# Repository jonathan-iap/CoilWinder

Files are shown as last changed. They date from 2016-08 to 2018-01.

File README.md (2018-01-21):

# CoilWinder

## Version : 1

### Abstract :

An evolutive coil winder machine based on *Arduino*.
The format of this machine can easily be adapted and upgraded for any coils.

---

### State of development :

  * Hardware -> functional
  * Software -> v1.0 : ok for coils production. Homing not working properly.

Software is write with the help of *platformIO* and *Eclipse*.
If you want to compile with *Arduino IDE* you need to create _*.ino_ file and add librairies in your path.

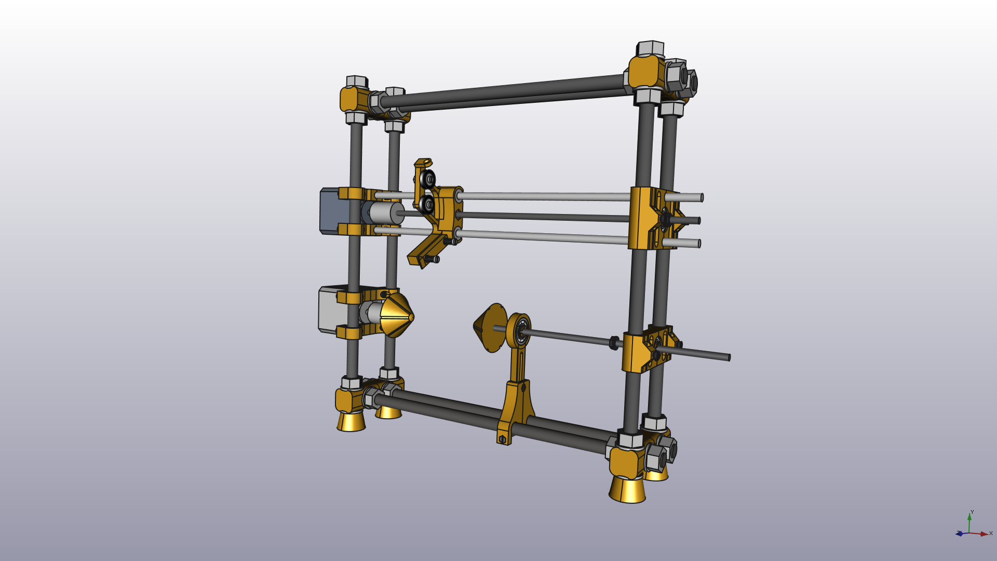
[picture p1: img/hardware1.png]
alt text Hardware view 1


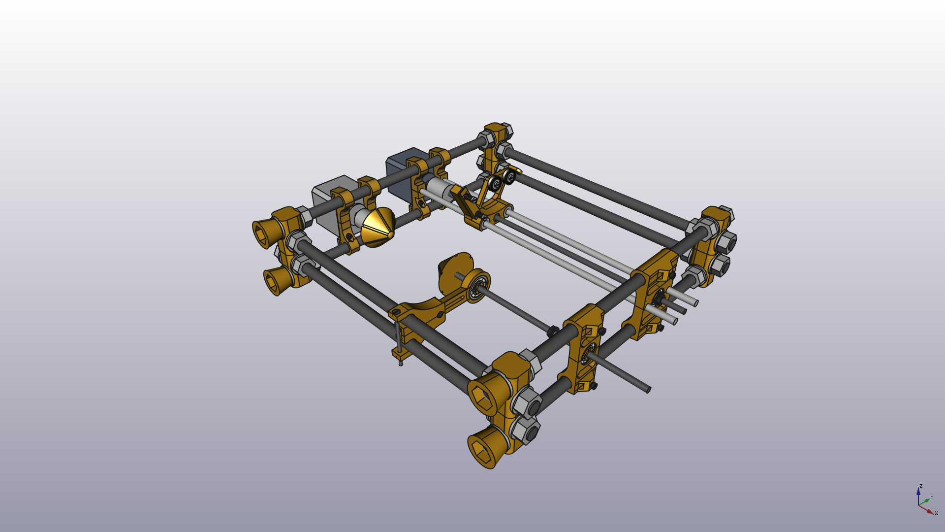
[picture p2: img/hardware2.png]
alt text Hardware view 2


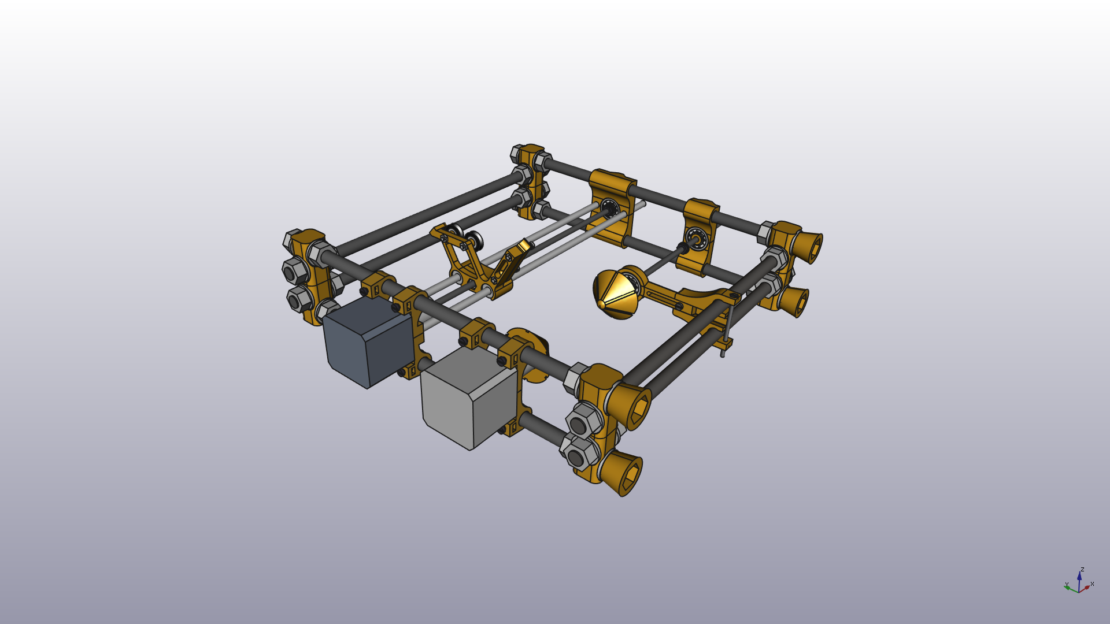
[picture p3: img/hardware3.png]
alt text Hardware view 3


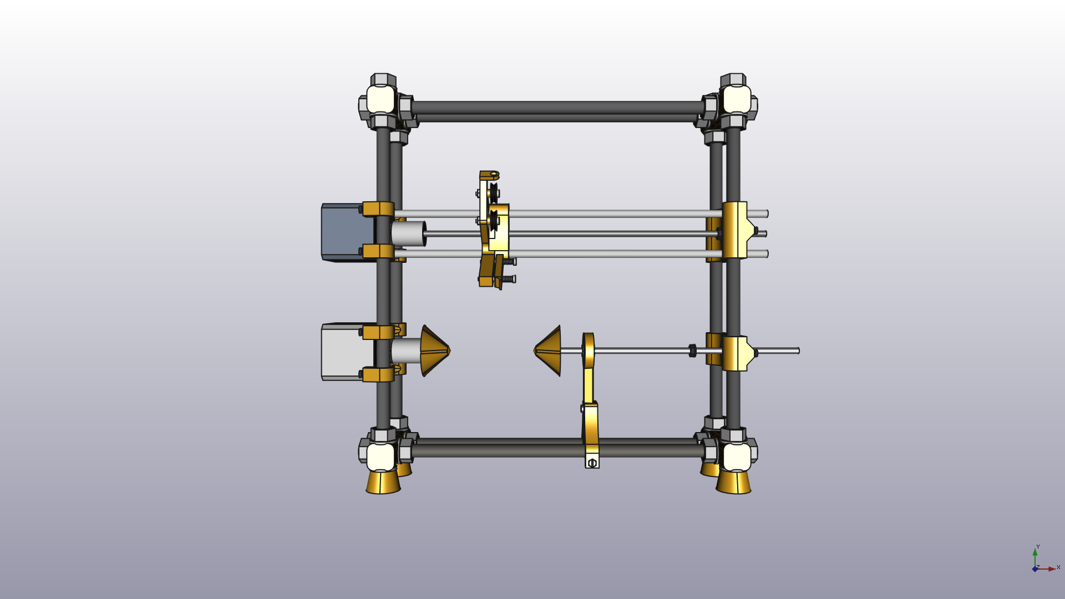
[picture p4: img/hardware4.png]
alt text Hardware view 4


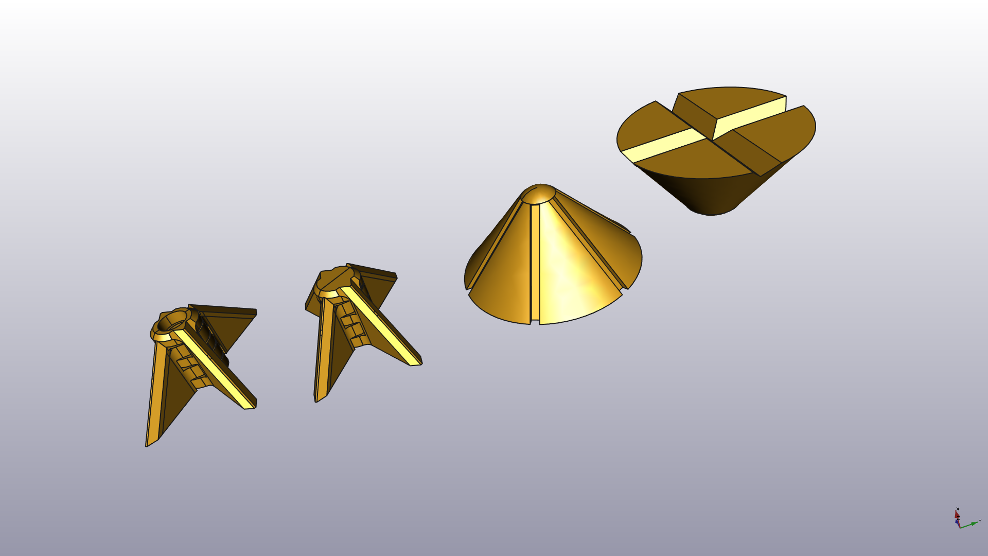
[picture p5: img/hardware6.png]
alt text Hardware view 6


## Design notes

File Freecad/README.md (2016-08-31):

# FreeCAD

Version used : 0.16
Macros used : bolts

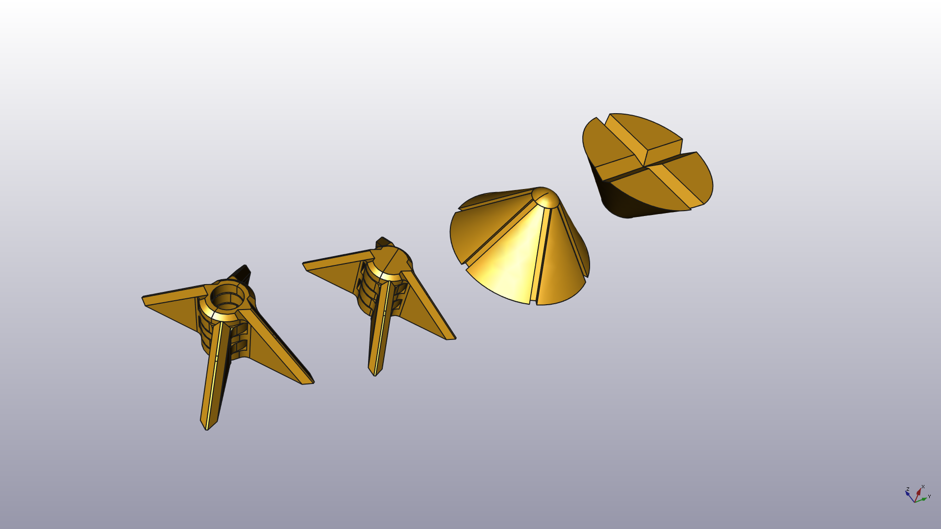
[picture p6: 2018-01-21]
img/hardware5.png

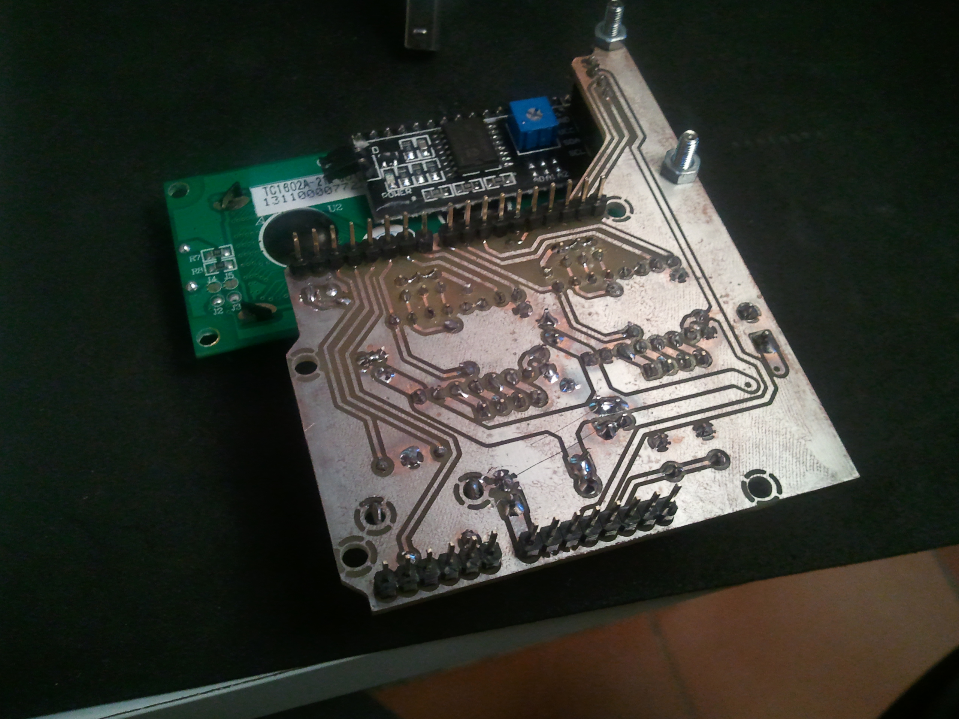
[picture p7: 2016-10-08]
img/2016-10-08 19.10.06.jpg

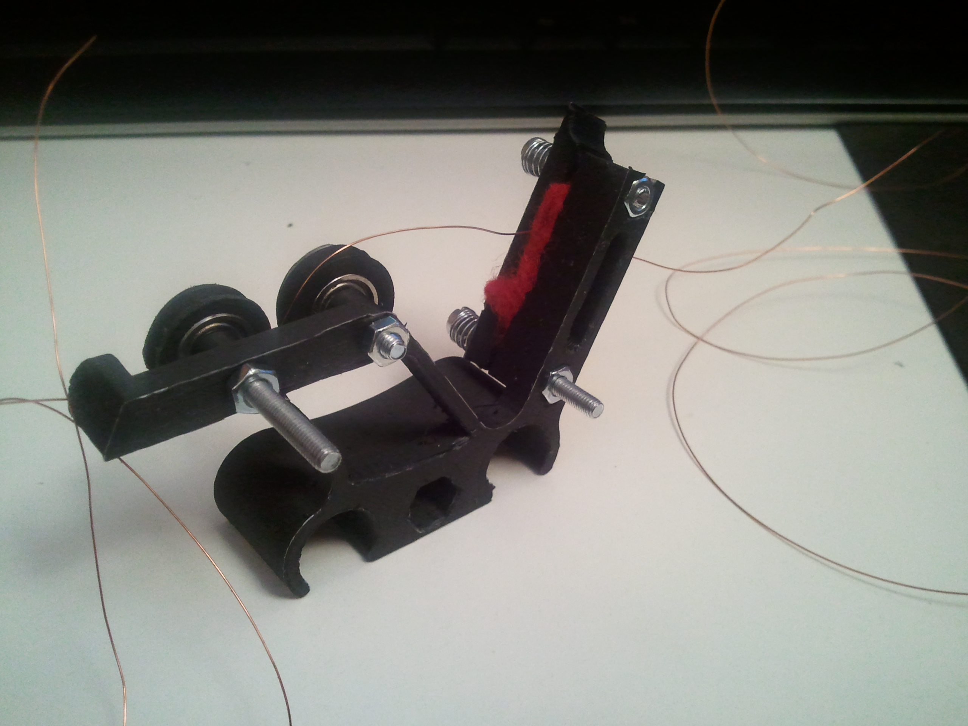
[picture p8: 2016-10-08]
img/2016-10-08 19.16.13.jpg

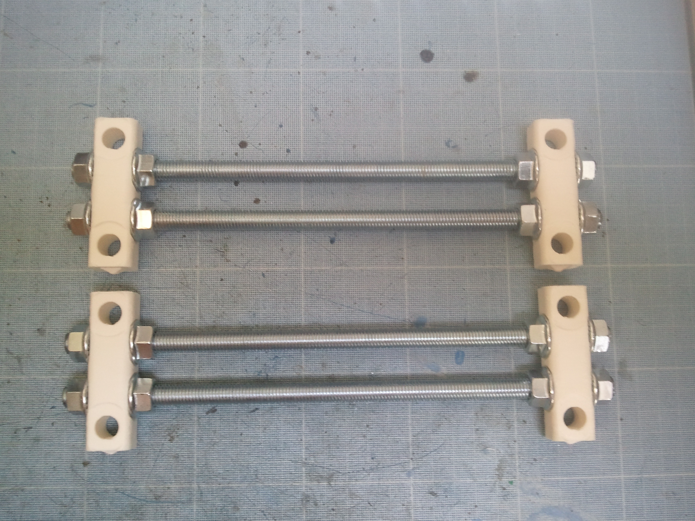
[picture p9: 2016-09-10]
img/2016-09-10 18.19.24.jpg

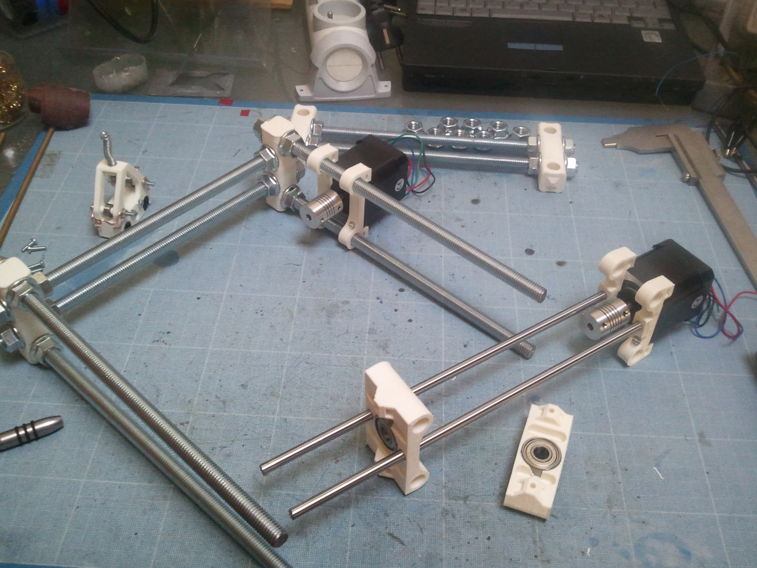
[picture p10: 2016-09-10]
img/2016-09-10 19.29.03.jpg

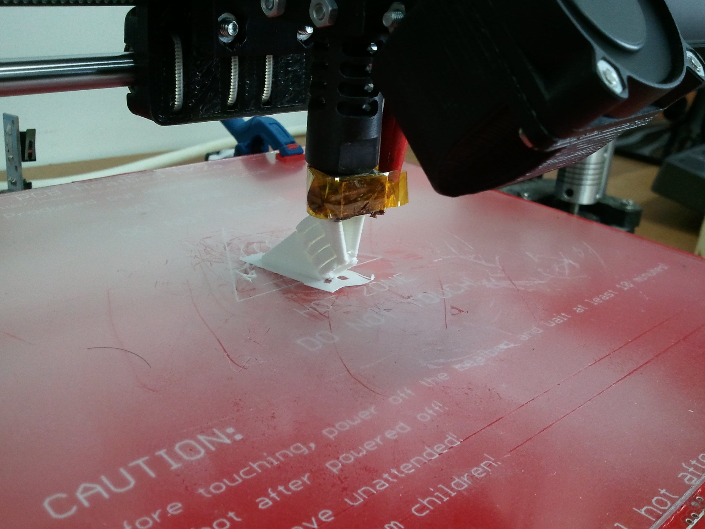
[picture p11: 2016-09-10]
img/2016-08-17 15.03.10.jpg

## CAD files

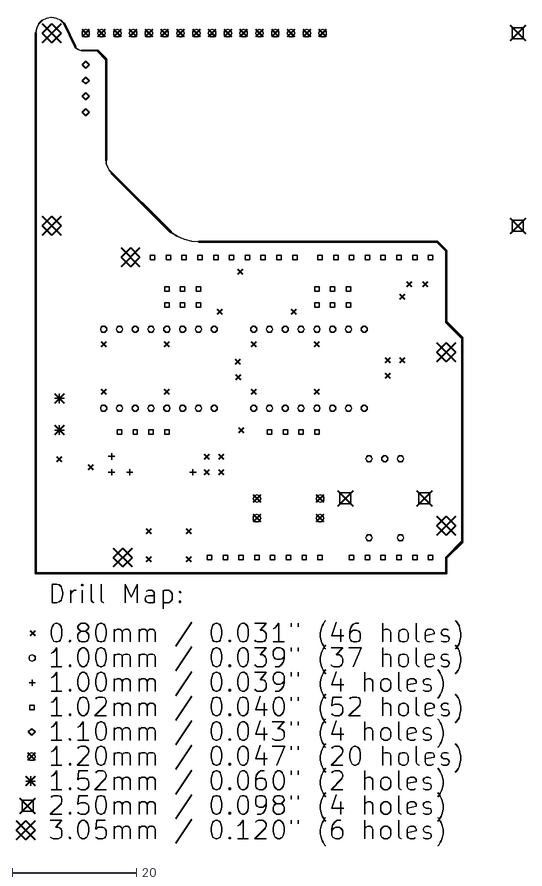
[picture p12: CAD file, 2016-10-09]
Kicad/shield_coil-winder/FAB/V1.1/shield_coil-winder-drl_map.dxf
81.9 x 133.5

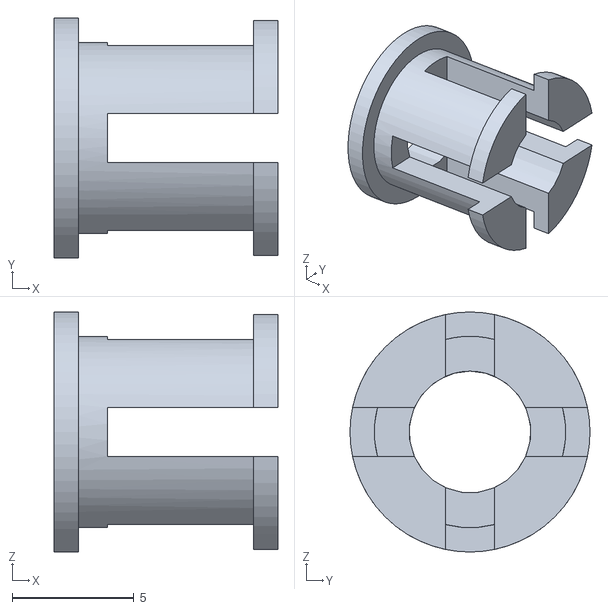
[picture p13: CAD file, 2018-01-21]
STL_export/entretoise pour roulement.stl
9.20 x 9.86 x 9.86

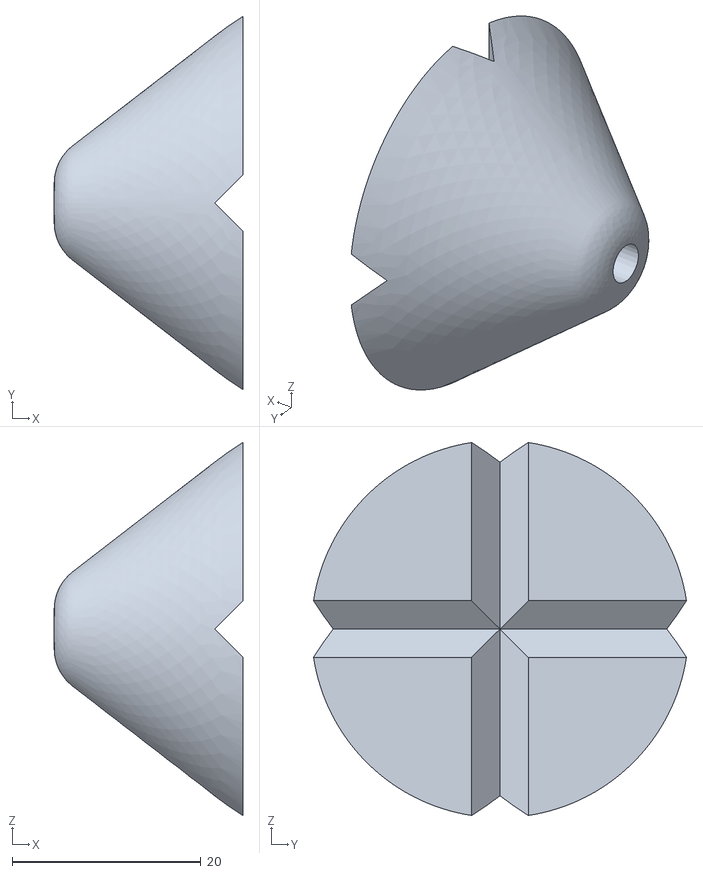
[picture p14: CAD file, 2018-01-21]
STL_export/centreur fixe pour plaque.stl
20.0 x 39.5 x 39.5

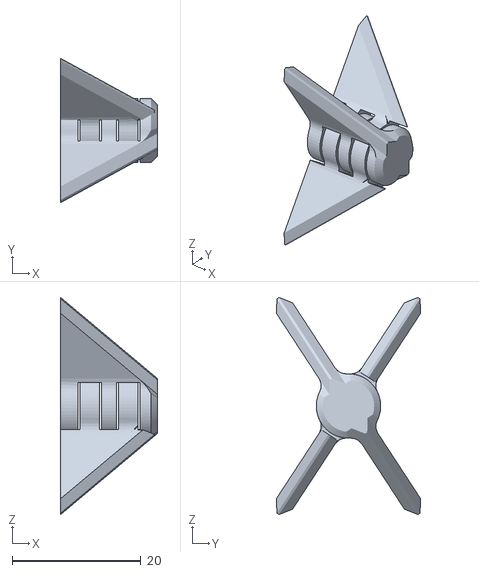
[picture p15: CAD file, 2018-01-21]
STL_export/centreur variable.stl
15.0 x 22.4 x 33.7

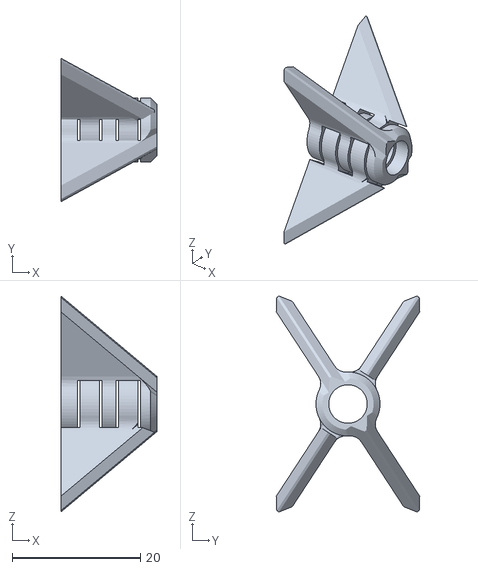
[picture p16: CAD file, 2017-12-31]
STL_export/centreur variable traversant.stl
15.0 x 22.4 x 33.7

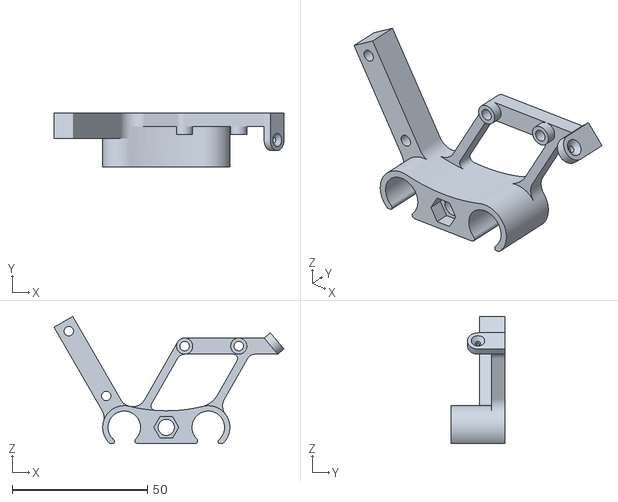
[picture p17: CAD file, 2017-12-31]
STL_export/Chariot_v0.4-LM6UU.stl
84.9 x 20.0 x 47.0

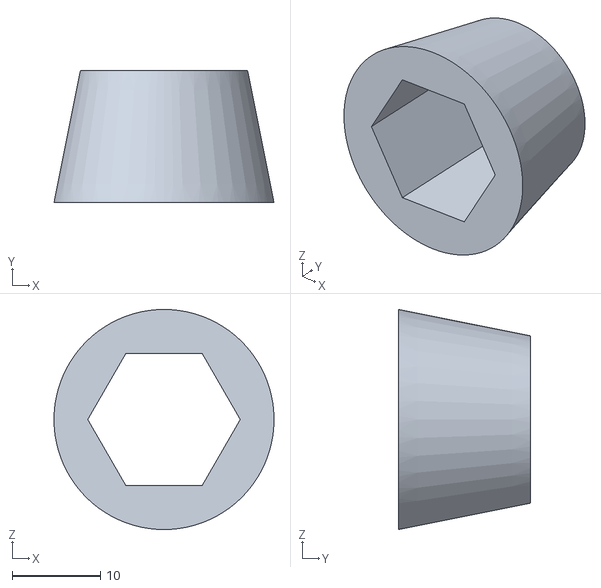
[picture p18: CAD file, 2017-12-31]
STL_export/pied.stl
25.0 x 15.0 x 25.0

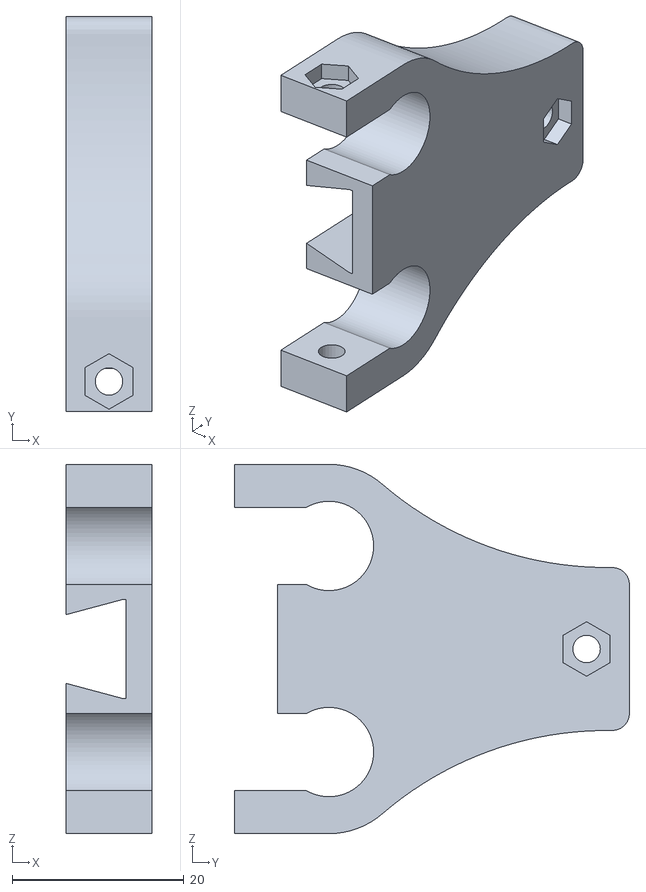
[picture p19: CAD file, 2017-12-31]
STL_export/bride axial.stl
10.0 x 46.0 x 43.0

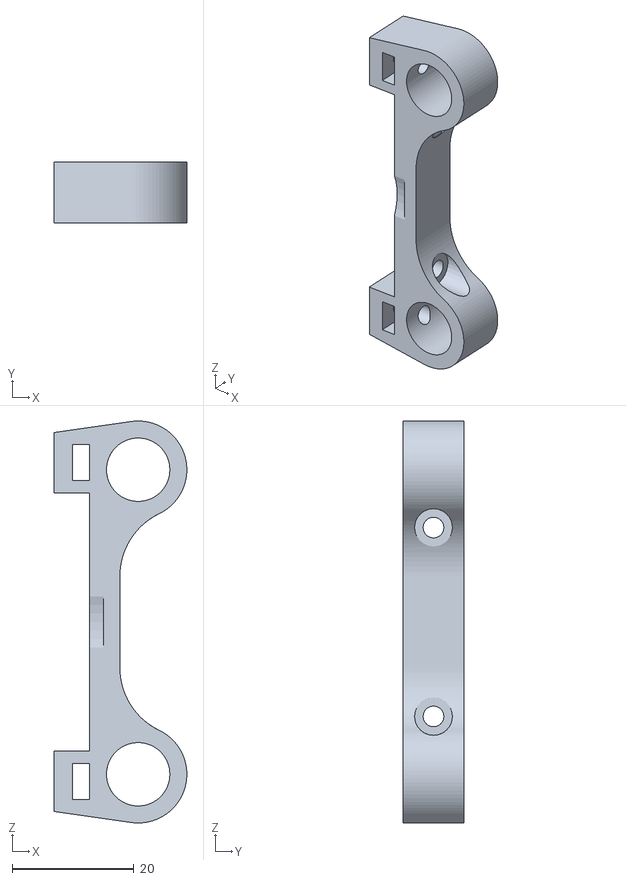
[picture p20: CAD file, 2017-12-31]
STL_export/support moteur bobine.stl
21.8 x 10.0 x 66.0

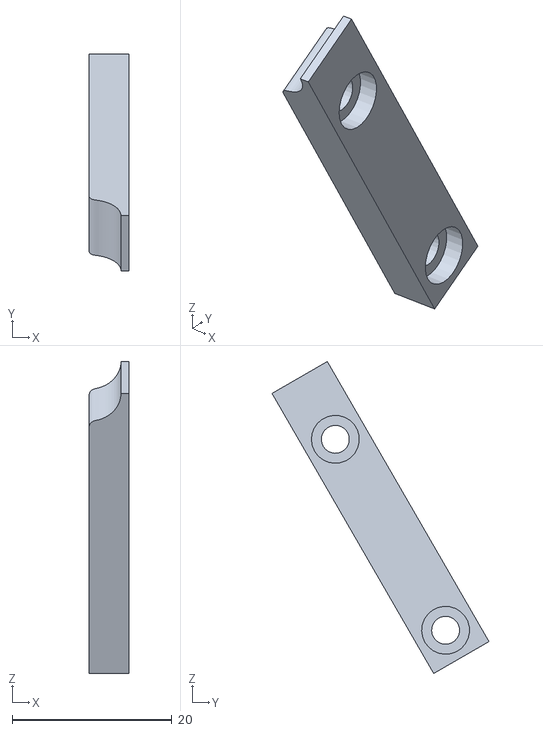
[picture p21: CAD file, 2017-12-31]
STL_export/patin pour chariot_v0.4.stl
5.00 x 27.2 x 39.1

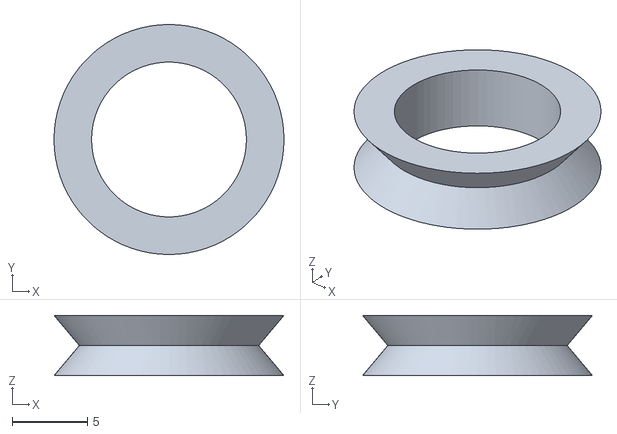
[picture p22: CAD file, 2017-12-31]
STL_export/poulie roulement 10x3x5.stl
15.3 x 15.3 x 4.00

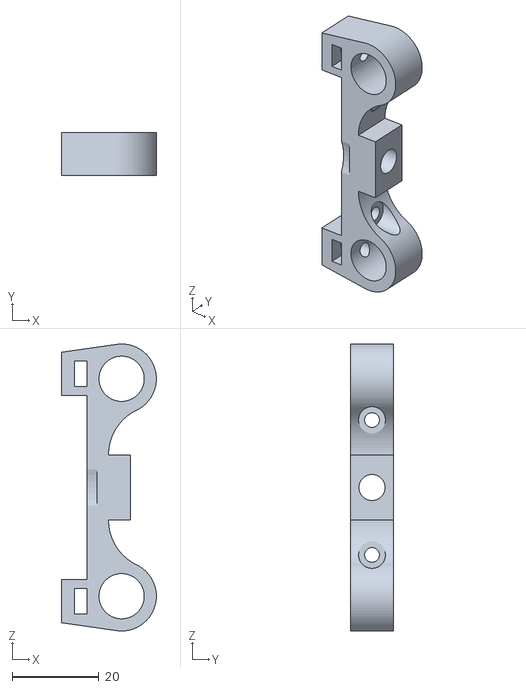
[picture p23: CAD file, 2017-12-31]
STL_export/support moteur chariot.stl
21.8 x 10.0 x 66.0

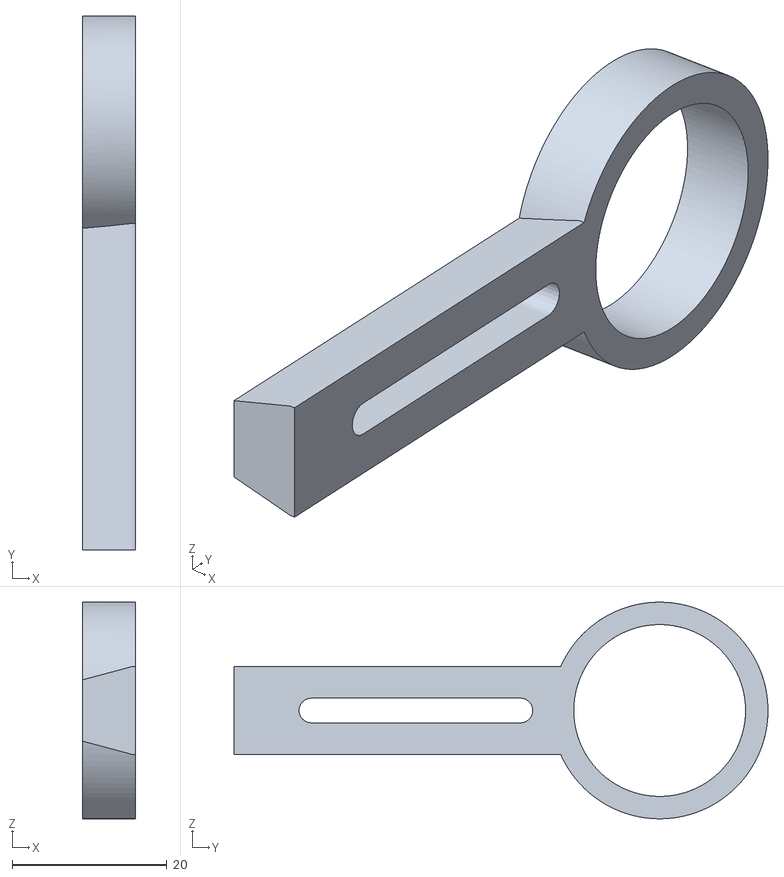
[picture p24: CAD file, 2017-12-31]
STL_export/support de bride axial.stl
6.90 x 69.0 x 28.0

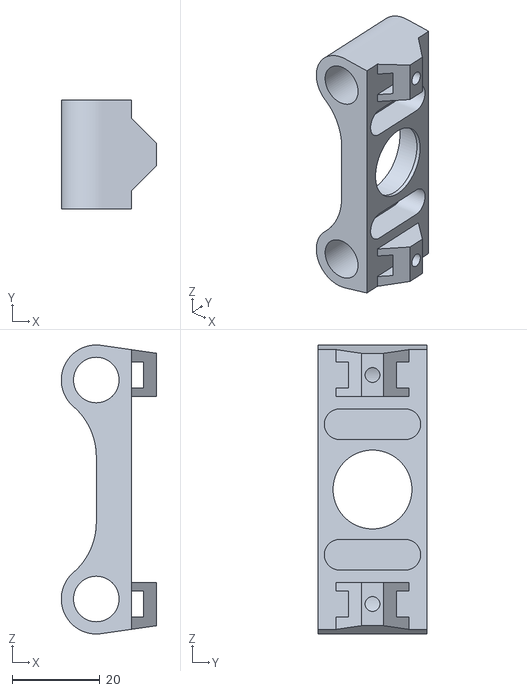
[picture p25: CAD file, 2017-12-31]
STL_export/support axe bobine_v0.2.stl
21.8 x 25.0 x 66.0

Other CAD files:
STL_export/centreur fixe conique.stl
STL_export/Chariot_v0.4-6x10x8.stl
STL_export/coin.stl
STL_export/support axe guide fil_v0.2.stl
Kicad/shield_coil-winder/FAB/V1.0/shield_coil-winder-drl_map.dxf

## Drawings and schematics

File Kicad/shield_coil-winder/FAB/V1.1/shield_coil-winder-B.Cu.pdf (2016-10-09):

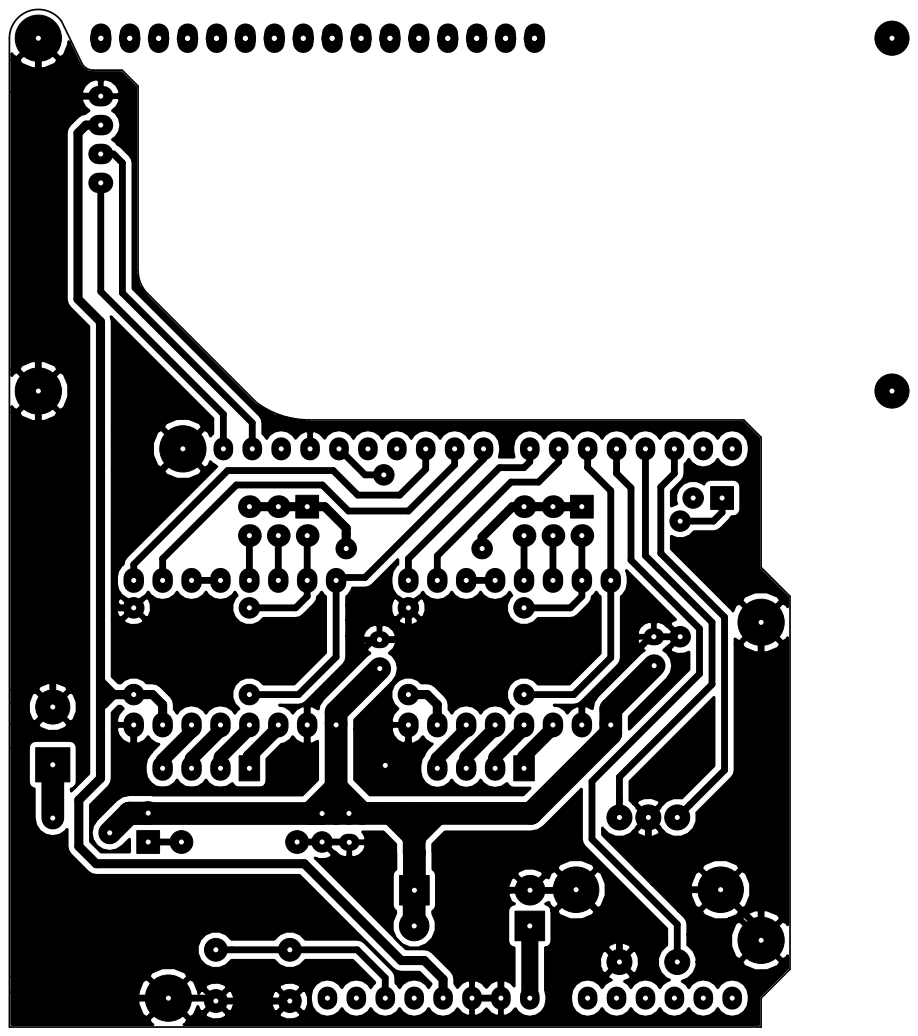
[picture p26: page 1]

Adding power status LED
File: shield_coil-winder.kicad_pcb Sheet: Author : Jonathan IAPICCO Correction footprint rotary encoder

Id: 1/1 Title: Shield coil winder for arduino UNO

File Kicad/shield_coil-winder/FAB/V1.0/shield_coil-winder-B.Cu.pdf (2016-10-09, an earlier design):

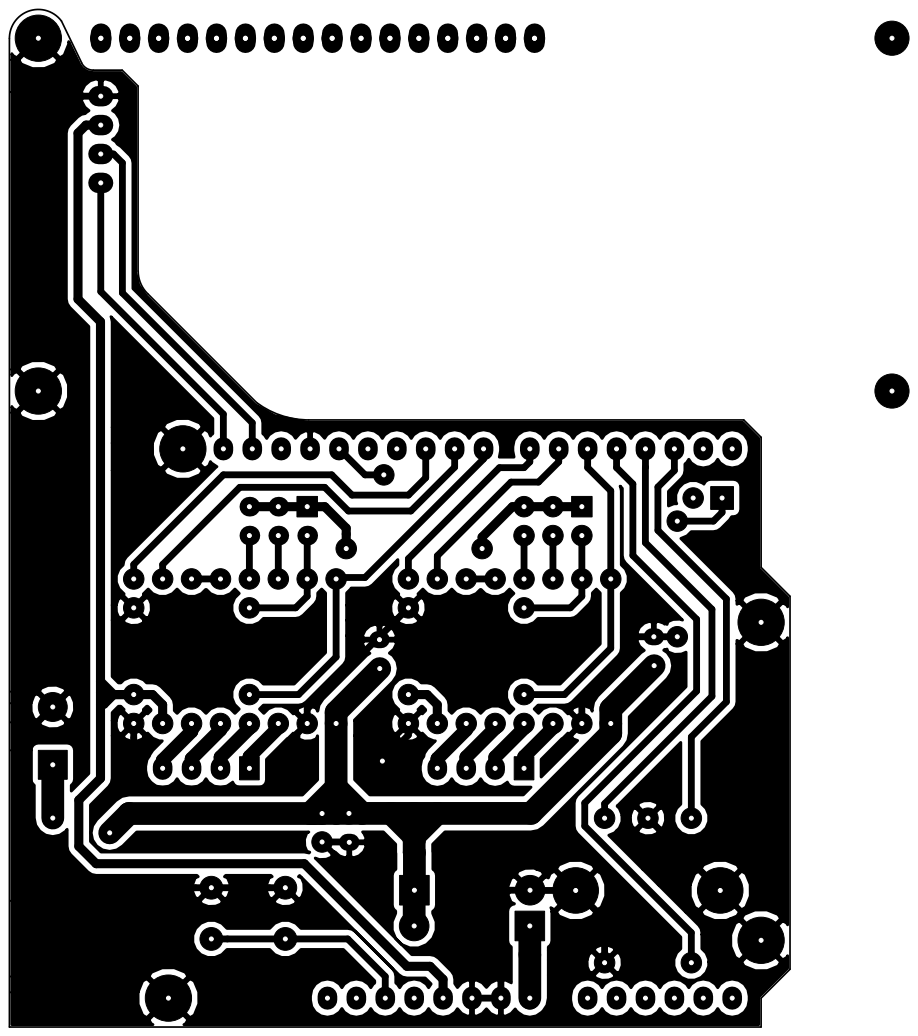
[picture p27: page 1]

File: shield_coil-winder.kicad_pcb Sheet: Author : Jonathan IAPICCO

Id: 1/1 Title: Shield coil winder for arduino UNO

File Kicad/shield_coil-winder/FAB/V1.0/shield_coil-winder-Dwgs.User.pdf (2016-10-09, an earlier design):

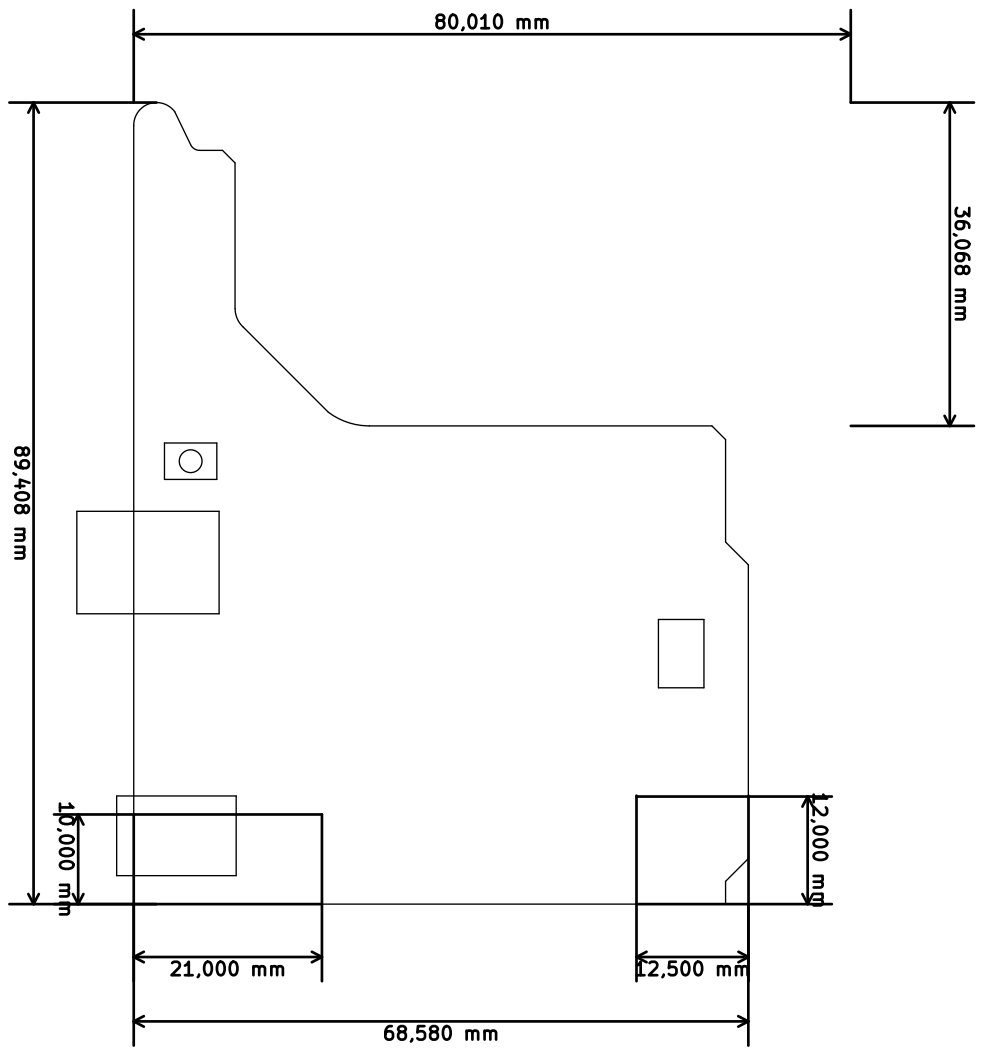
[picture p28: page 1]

File: shield_coil-winder.kicad_pcb Sheet: Author : Jonathan IAPICCO 36,068 mm

Id: 1/1 Title: Shield coil winder for arduino UNO

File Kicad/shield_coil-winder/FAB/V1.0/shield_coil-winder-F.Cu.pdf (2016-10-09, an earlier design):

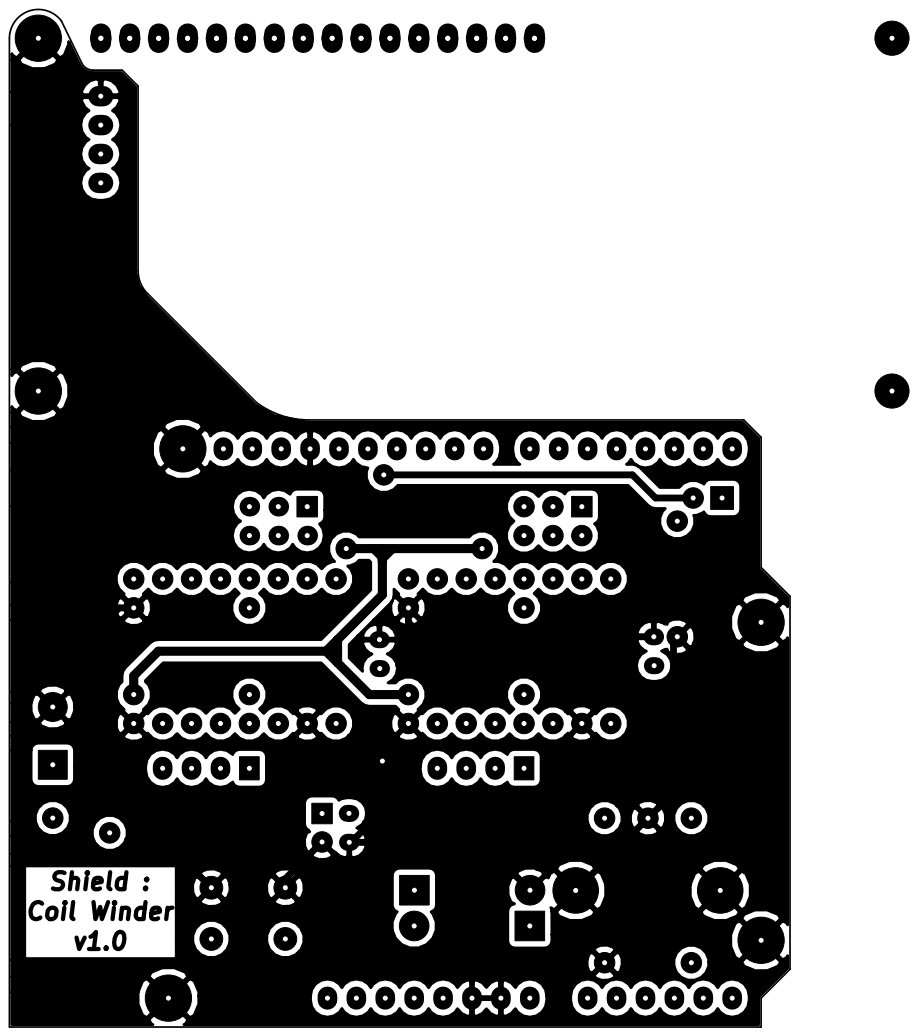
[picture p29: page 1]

File: shield_coil-winder.kicad_pcb Sheet: Author : Jonathan IAPICCO Shield : Coil Winder v1.0

Id: 1/1 Title: Shield coil winder for arduino UNO

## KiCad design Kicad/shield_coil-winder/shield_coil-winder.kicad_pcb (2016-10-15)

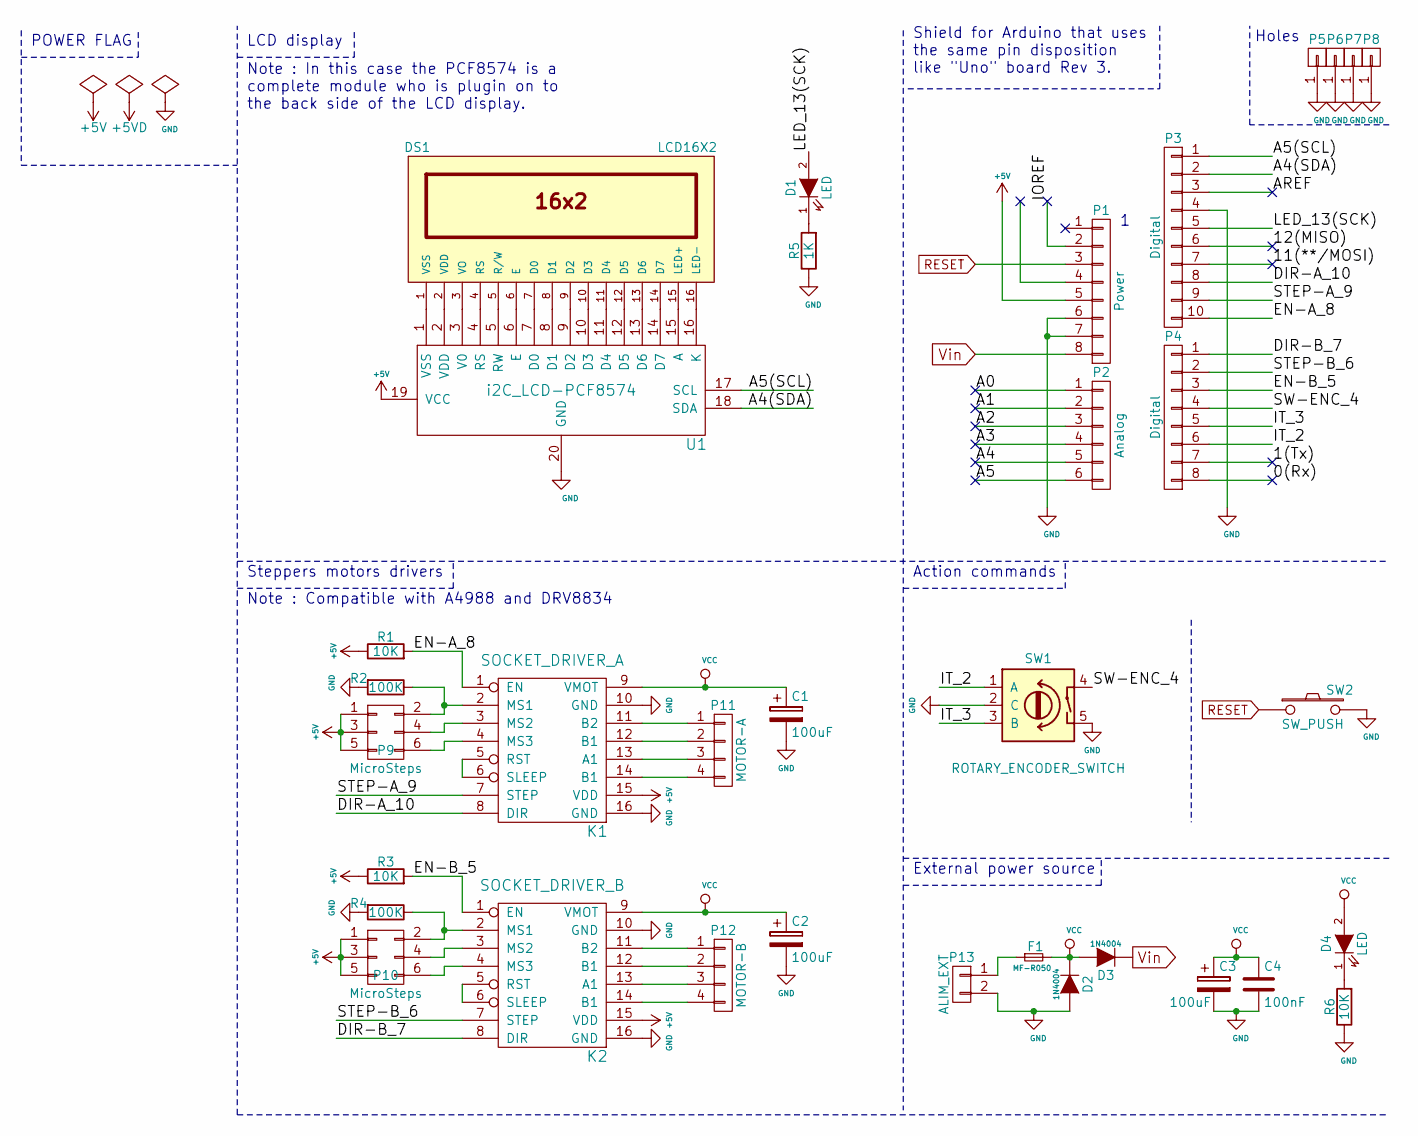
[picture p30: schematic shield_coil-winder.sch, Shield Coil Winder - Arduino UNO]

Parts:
C1, C2, C3: 100uF; C_Horiz_15.5x6.5
C4: 100nF; C_Disc_D3_P2.5
D1, D4: LED; LED-3MM
D2, D3: 1N4004; Diode_DO-41_SOD81_Horizontal_RM10
DS1: LCD16X2; WC1602A
F1: MF-R050; RV_Disc_D7_W3.4_P5
K1: SOCKET_DRIVER_A; Driver_Socket
K2: SOCKET_DRIVER_B; Driver_Socket
P1: Power; Socket_Strip_Arduino_1x08
P2: Analog; Socket_Strip_Arduino_1x06
P3: Digital; Socket_Strip_Arduino_1x10
P4: Digital; Socket_Strip_Arduino_1x08
P5, P6, P7, P8: CONN_01X01; Arduino_1pin
P9, P10: MicroSteps; Pin_Header_Straight_2x03
P11: MOTOR-A; Pin_Header_Straight_1x04
P12: MOTOR-B; Pin_Header_Straight_1x04
P13: ALIM_EXT; bornier2
R1, R3, R6: 10K; Resistor_Horizontal_RM10mm
R2, R4: 100K; Resistor_Horizontal_RM10mm
R5: 1K; Resistor_Horizontal_RM10mm
SW1: ROTARY_ENCODER_SWITCH; Rotary_encoder-ALPS
SW2: SW_PUSH; SW_PUSH_6mm
U1: i2C_LCD-PCF8574; PCF8574_Board

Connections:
+5V: K1.15 (VDD), K2.15 (VDD), P1.5, P9.1, P9.3, P9.5, P10.1, P10.3, P10.5, R1.1, R3.1, U1.19 (VCC)
/0(Rx): P4.8
/1(Tx): P4.7
/11(**/MOSI): P3.7
/12(MISO): P3.6
/A0: P2.1
/A1: P2.2
/A2: P2.3
/A3: P2.4
/A4: P2.5
/A4(SDA): P3.2, U1.18 (SDA)
/A5: P2.6
/A5(SCL): P3.1, U1.17 (SCL)
/AREF: P3.3
/DIR-A_10: K1.8 (DIR), P3.8
/DIR-B_7: K2.8 (DIR), P4.1
/EN-A_8: K1.1 (EN), P3.10, R1.2
/EN-B_5: K2.1 (EN), P4.3, R3.2
/IOREF: P1.2
/IT_2: P4.6, SW1.1 (A)
/IT_3: P4.5, SW1.3 (B)
/LED_13(SCK): D1.2 (A), P3.5
/STEP-A_9: K1.7 (STEP), P3.9
/STEP-B_6: K2.7 (STEP), P4.2
/SW-ENC_4: P4.4, SW1.4
GND: C1.2, C2.2, C3.2, C4.2, D2.2 (A), DS1.0, K1.10 (GND), K1.16 (GND), K2.10 (GND), K2.16 (GND), P1.6, P1.7, P3.4, P5.1, P6.1, P7.1, P8.1, P13.2, R2.2, R4.2, R5.1, R6.1, SW1.2 (C), SW1.5, SW2.2, U1.20 (GND)
unnamed: D1.1 (K), R5.2
unnamed: D4.1 (K), R6.2
unnamed: DS1.1 (VSS), U1.1 (VSS)
unnamed: DS1.2 (VDD), U1.2 (VDD)
unnamed: DS1.3 (VO), U1.3 (V0)
unnamed: DS1.4 (RS), U1.4 (RS)
unnamed: DS1.5 (R/W), U1.5 (RW)
unnamed: DS1.6 (E), U1.6 (E)
unnamed: DS1.7 (D0), U1.7 (D0)
unnamed: DS1.8 (D1), U1.8 (D1)
unnamed: DS1.9 (D2), U1.9 (D2)
unnamed: DS1.10 (D3), U1.10 (D3)
unnamed: DS1.11 (D4), U1.11 (D4)
unnamed: DS1.12 (D5), U1.12 (D5)
unnamed: DS1.13 (D6), U1.13 (D6)
unnamed: DS1.14 (D7), U1.14 (D7)
unnamed: DS1.15 (LED+), U1.15 (A)
unnamed: DS1.16 (LED-), U1.16 (K)
unnamed: F1.1, P13.1
unnamed: K1.2 (MS1), P9.2, R2.1
unnamed: K1.3 (MS2), P9.4
unnamed: K1.4 (MS3), P9.6
unnamed: K1.5 (RST), K1.6 (SLEEP)
unnamed: K1.11 (B2), P11.1
unnamed: K1.12 (B1), P11.2
unnamed: K1.13 (A1), P11.3
unnamed: K1.14 (B1), P11.4
unnamed: K2.2 (MS1), P10.2, R4.1
unnamed: K2.3 (MS2), P10.4
unnamed: K2.4 (MS3), P10.6
unnamed: K2.5 (RST), K2.6 (SLEEP)
unnamed: K2.11 (B2), P12.1
unnamed: K2.12 (B1), P12.2
unnamed: K2.13 (A1), P12.3
unnamed: K2.14 (B1), P12.4
RESET: P1.3, SW2.1
VCC: C1.1, C2.1, C3.1, C4.1, D2.1 (K), D3.2 (A), D4.2 (A), F1.2, K1.9 (VMOT), K2.9 (VMOT)
Vin: D3.1 (K), P1.8

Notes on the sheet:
Holes
Shield for Arduino that uses the same pin disposition like "Uno" board Rev 3.
Action commands
External power source
Steppers motors drivers
LCD display
POWER FLAG
Note : Compatible with A4988 and DRV8834
Note : In this case the PCF8574 is a complete module who is plugin on to the back side of the LCD display.

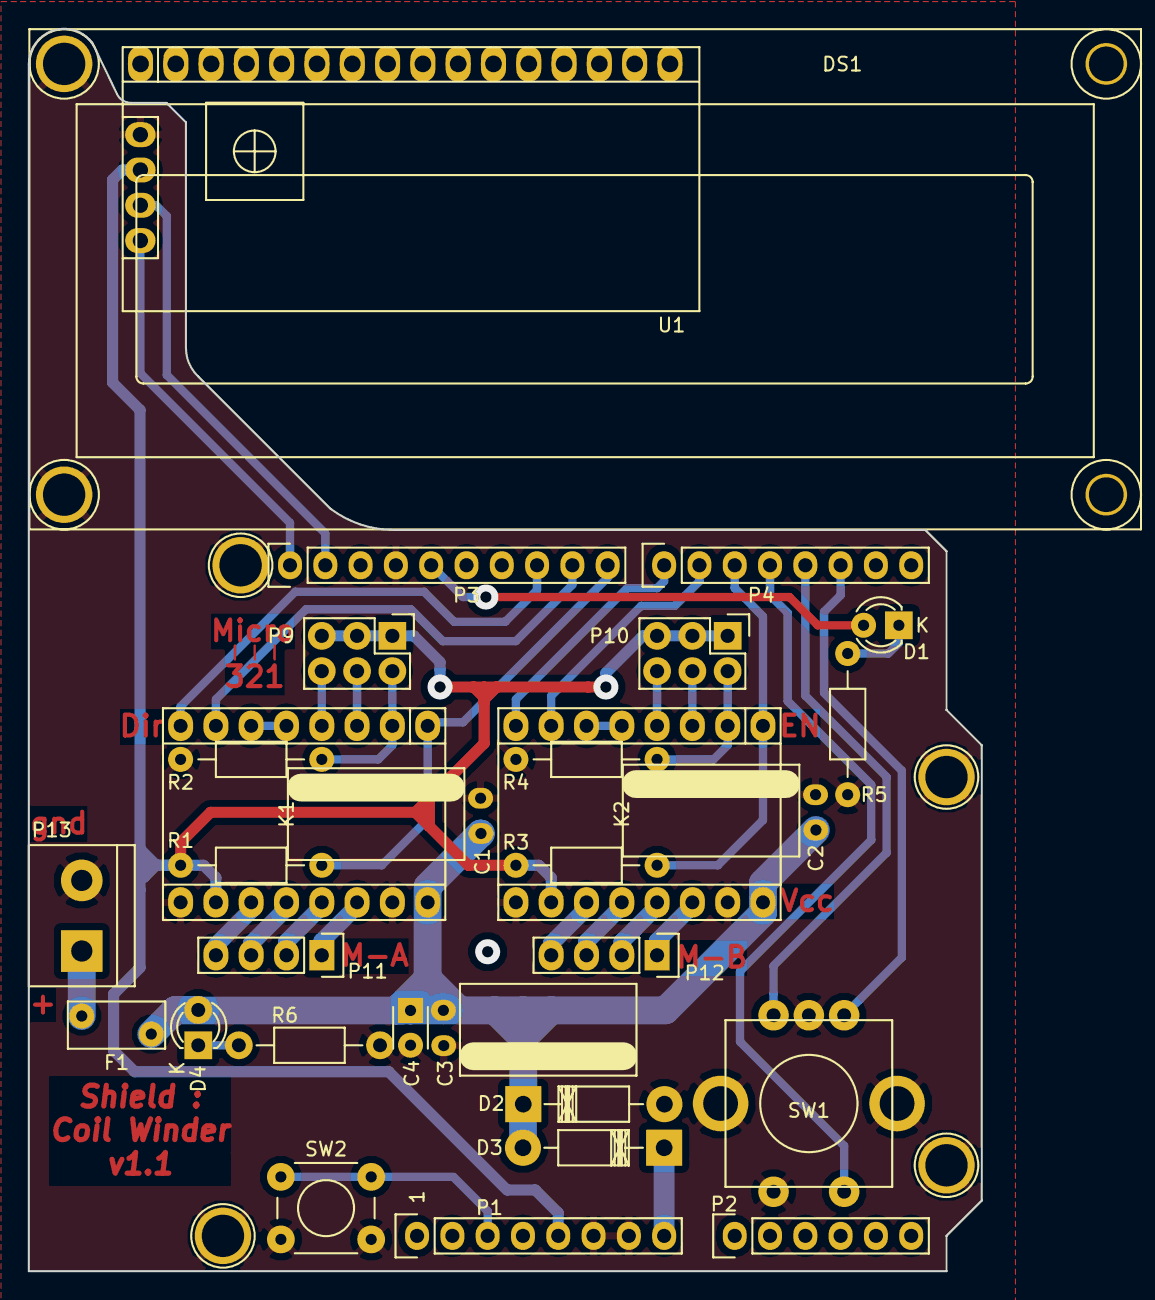
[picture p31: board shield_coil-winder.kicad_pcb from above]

Board: 2 copper layers, 68.6 x 89.4 mm, 34 parts (0 on the bottom side), 52 nets.

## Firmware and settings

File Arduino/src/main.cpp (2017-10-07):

/* Coil Winder program.

   History
   =======
   2016/OCT/13  - First version
 */

// libraries ------------------------------------------------------------------
#include "Arduino.h"
#include "Configuration.h"
#include "Display.h"
#include "ClickEncoder.h"
#include "TimerOne.h"
#include "MenuStructure.h"
#include "MsTimer2.h"

// Declare objects ------------------------------------------------------------
ClickEncoder Encoder;
Menu::Engine *engine;
Display display;
Coil CoilWinding(&Encoder, &display);
Setting setting(&Encoder, &display, &CoilWinding);

// Global Variables -----------------------------------------------------------
uint8_t systemState = state_DEFAULT;
uint8_t previousSystemState = state_NONE;
uint8_t menuItemsVisible = LCD_LINES;
int16_t encMovement;
int16_t encAbsolute;
int16_t tmpValue = 0;

bool updateMenu = false;
bool lastEncoderAccelerationState = true;


// Functions ------------------------------------------------------------------
void timerEncoder(void)
{
  Encoder.service();
}



/* SETUP ---------------------------------------------------------------------*/
void setup()
{
  // Debug section
#ifdef DEBUG
  Serial.begin(BAUDRATE);

  Serial.print("\n\nbegin\n\n");
  delay(1000);
#endif
  // Lcd initialization
  display.begin();
  // For rotary encoder
  MsTimer2::set(1, timerEncoder); // 1ms
  MsTimer2::start();
  // Menu begin
  engine = new Menu::Engine(&Menu::NullItem);
  // Init timer for motors and pins
  M_init();
  // Pin initialization
  pinMode(13, OUTPUT);

  //start Menu -> read memory and display version
  engine->navigate(&miHome);
}

/* LOOP ----------------------------------------------------------------------*/
void loop()
{
  // handle encoder
  encMovement = Encoder.getValue();
  if (encMovement)
    {
      encAbsolute += encMovement;

      switch(systemState)
      {
	case state_MOVE :
	  {
	    engine->navigate((encMovement > 0) ? engine->getNext() : engine->getPrev());
	    updateMenu = true;
	    break;
	  }

	case state_EDIT :
	  {
	    (encMovement > 0) ? tmpValue++ : tmpValue--;
	    updateMenu = true;
	    break;
	  }
      }
    }

  // handle button
  switch (Encoder.getButton())
  {

    case ClickEncoder::Clicked:
      {
	// Enter in item
	if(systemState == state_MOVE)
	  {
	    engine->invoke();
	    updateMenu = true;
	  }
	else if(systemState == state_EDIT)
	  {
	    systemState = state_MOVE;
	    engine->navigate(engine->getParent());
	    updateMenu = true;
	  }
	else
	  {
	    // enter settings menu
	    engine->navigate(&miSetWinding);

	    systemState = state_MOVE;
	    previousSystemState = systemState;
	    updateMenu = true;
	  }
	break;
      }
    case ClickEncoder::Held:{break;}
    case ClickEncoder::Open:{break;}
  }

  if(systemState == state_BACK)
    {
      systemState = state_MOVE;
      engine->navigate(engine->getParent());
      updateMenu = true;
    }

  // update LCD
  if (updateMenu)
    {
      updateMenu = false;

      if (!encMovement)
	{
	  // clear menu on child/parent navigation
	  display.clear();
	}
      // render the menu
      engine->render(renderMenuItem, menuItemsVisible);
    }
}

/* ( THE END ) */

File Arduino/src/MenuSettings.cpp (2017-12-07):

/*
 * MenuSettings.cpp
 *
 *  Created on: 2 déc. 2016
 *      Author: jo
 */
#include "MenuSettings.h"

Setting::Setting(ClickEncoder *p_Encoder, Display *p_Display, Coil *p_Coil)
:  _idValue(0),
   _tmp_id(0),
   p_arrayValue(0),
   _sizeBuffValue(0),
   p_floatingValue(0),
   p_intValue(0),
   _speedPercent(100),
   _positionAB(0),
   _index(0),
   _minIndex(0),
   _homePosition(0)
{
  _Encoder = p_Encoder;
  _Display = p_Display;
  _Coil = p_Coil;
}




Setting::~Setting(){}




/******************************************************************************
 * brief   : For edit values
 * details : Drive all functions to set value in edit mode.
 ******************************************************************************/
void Setting::actionMenu(const uint8_t id)
{
  _idValue = id;
  _tmp_id = id;

  p_intValue = NULL;
  p_floatingValue  = NULL;

  setValueFromId();
  navigationEngine();
}


void Setting::actionMenu(const uint8_t id, bool isFloat)
{
  _idValue = id;
  _tmp_id = id;

  isFloat ? p_intValue = NULL : p_floatingValue  = NULL;

  setValueFromId();
  navigationEngine();
}


void Setting::actionMenu(const uint8_t id, char tmp_buffValue[], float *tmp_valFromBuff)
{
  _idValue = id;

  p_arrayValue     = tmp_buffValue;
  p_floatingValue  = tmp_valFromBuff;
  p_intValue       = NULL;

  setValueFromId();
  navigationEngine();
}

void Setting::actionMenu(const uint8_t id, char tmp_buffValue[], uint16_t *tmp_valFromBuff)
{
  _idValue = id;

  p_arrayValue     = tmp_buffValue;
  p_intValue       = tmp_valFromBuff;
  p_floatingValue  = NULL;

  setValueFromId();
  navigationEngine();
}

/******************************************************************************
 * brief   : Assign value and action
 * details : Depending the Id, we set value and action if needed.
 ******************************************************************************/
void Setting::setValueFromId()
{
  switch (_idValue)
  {
    case id_HOME :
      {
	setValues(MSG_HOMING, ACTIONBAR_SETHOME, SIZE_AB_SETHOME, LCD_LINES);
	break;
      }
    case id_WIRESIZE :
      {
	setValues(MSG_WIRE_SIZE, _buff_WireSize, BUFFSIZE_WIRE, &WireSize, UNIT_MM,
		  ACTIONBAR_SETVALUE, SIZE_AB_SETVALUE, LCD_LINES);
	break;
      }
    case id_COILLENGTH :
      {
	setValues(MSG_COIL_LENGTH, _buff_CoilLength, BUFFSIZE_COIL, &CoilLength, UNIT_MM,
		  ACTIONBAR_SETVALUE, SIZE_AB_SETVALUE, LCD_LINES);
	break;
      }
    case id_TURNS :
      {
	setValues(MSG_TURNS, _buff_Turns, BUFFSIZE_TURNS, &Turns, UNIT_TR,
		  ACTIONBAR_SETVALUE, SIZE_AB_SETVALUE, LCD_LINES);
	break;
      }
    case id_W_SENSE :
      {
	setValues(MSG_EMPTY, ACTIONBAR_SENSE_SAVE, SIZE_AB_SENSE_SAVE, LCD_LINES);
	break;
      }
    case id_C_SENSE :
      {
	setValues(MSG_EMPTY, ACTIONBAR_SENSE_SAVE, SIZE_AB_SENSE_SAVE, LCD_LINES);
	break;
      }
    case id_MAX_SPEED :
      {
	setValues(MSG_MAX_SPEED, _buff_MaxSpeed, BUFFSIZE_MAX_SPEED, &MaxSpeed, UNIT_RPM,
		  ACTIONBAR_SETVALUE, SIZE_AB_SETVALUE, LCD_LINES);
	break;
      }
    case id_MIN_SPEED :
      {
	setValues(MSG_MIN_SPEED, _buff_MinSpeed, BUFFSIZE_MIN_SPEED, &MinSpeed, UNIT_RPM,
		  ACTIONBAR_SETVALUE, SIZE_AB_SETVALUE, LCD_LINES);
	break;
      }
    case id_ACC_DELAY :
      {
	setValues(MSG_ACC_DELAY, _buff_AccDelay, BUFFSIZE_ACC_DELAY, &AccDelay, UNIT_US,
		  ACTIONBAR_SETVALUE, SIZE_AB_SETVALUE, LCD_LINES);
	break;
      }
    case id_ACC_INCR :
      {
	setValues(MSG_ACC_INCR, _buff_AccIncr, BUFFSIZE_ACC_INCR, &AccIncr, UNIT_STEP,
		  ACTIONBAR_SETVALUE, SIZE_AB_SETVALUE, LCD_LINES);
	break;
      }
    case id_MOVE_CARRIAGE :
      {
	_tmp_id = id_MOVE_CARRIAGE;
	setValues(MSG_MOVE, COUNTOF(INIT_MOV_CAR), UNIT_MM, ACTIONBAR_MOVE, SIZE_AB_MOVE,
		  LCD_LINES);
	break;
      }
    case id_MOVE_COIL :
      {
	_tmp_id = id_MOVE_COIL;
	setValues(MSG_MOVE, COUNTOF(INIT_MOV_COIL), UNIT_TR, ACTIONBAR_MOVE, SIZE_AB_MOVE,
		  LCD_LINES);
	break;
      }
    case id_GO_HOME :
      {
	setValues(MSG_EMPTY, ACTIONBAR_CHOICE, SIZE_AB_CHOICE, LCD_LINES);
	break;
      }
    case id_RESET :
      {
	setValues(MSG_RESET, ACTIONBAR_CHOICE, SIZE_AB_CHOICE, LCD_LINES);
	break;
      }
    case id_RAZ :
      {
	setValues(MSG_RAZ, ACTIONBAR_CHOICE, SIZE_AB_CHOICE, LCD_LINES);
	break;
      }
    case id_NEW :
      {
	setValues(MSG_NEW_COIL, ACTIONBAR_CHOICE, SIZE_AB_CHOICE, LCD_LINES);
	break;
      }
    case id_RESUME :
      {
	setValues(MSG_RESUME, ACTIONBAR_CHOICE, SIZE_AB_CHOICE, LCD_LINES);
	break;
      }
    case id_RESUME_SAVE :
      {
	setValues(MSG_RESUME_SAVED, ACTIONBAR_CHOICE, SIZE_AB_CHOICE, LCD_LINES);
	break;
      }
  }
}
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

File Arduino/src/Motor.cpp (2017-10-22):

#include "Motor.h"

struct motor
{
  volatile bool en = DISABLE;
  volatile bool dir = CLOCK;
  volatile uint16_t steps = 0;
  volatile uint16_t tr = 0;
  volatile uint16_t tic = 0;
};
struct motor coil, carriage;

volatile uint8_t M_engineAction = 0;

volatile uint16_t M_speedSet = 0;
volatile uint16_t M_minSpeed = 0;

volatile uint16_t M_targetPass = 0;
volatile uint16_t M_stepsPerPass = 0;
volatile uint16_t M_targetTr = 0;
volatile uint16_t M_stepsPerTr = 0;

volatile uint16_t M_stepsInterval = 0;
volatile uint16_t M_stepsRest = 0;
volatile uint16_t M_stepsAdd = 0;

volatile uint16_t M_countInterval = 0;

volatile bool M_isCoilFastest = false;
volatile bool M_isFinished = false;
volatile bool M_isSuperior = false;
volatile bool M_isStepAddMode = false;

void M_init()
{
  Timer1.initialize(MOTOR_INT);

  pinMode(PIN_COIL_DIR , OUTPUT);
  pinMode(PIN_COIL_STEP, OUTPUT);
  pinMode(PIN_COIL_EN  , OUTPUT);

  pinMode(PIN_CARR_DIR , OUTPUT);
  pinMode(PIN_CARR_STEP, OUTPUT);
  pinMode(PIN_CARR_EN  , OUTPUT);

  digitalWrite(PIN_COIL_EN, DISABLE);
  digitalWrite(PIN_CARR_EN, DISABLE);
}

void M_start()
{
  M_isFinished = false;

  Timer1.attachInterrupt(M_engine);
}


void M_stop()
{
  Timer1.detachInterrupt();

  WRITE(PIN_COIL_EN, DISABLE);
  WRITE(PIN_CARR_EN, DISABLE);
}


/******************************************************************************
 * brief   : Engine for motor
 * details : Divide the timer tic to create accurate displacement.
 *
 * Fix timer callback each 10us :           Tic++...
 *   _    _    _    _    _    _    _    _   v_    _    _    _    _    _    _    _
 * _| |__| |__| |__| |__| |__| |__| |__| |__| |__| |__| |__| |__| |__| |__| |__| |
 *
 * Step for one motor constant speed, exemple : one step at each 4 tics
 *   _              _              _              _              _              _
 * _| |____________| |____________| |____________| |____________| |____________| |
 *
 * For acceleration step per tic is decrease depending a constant delay:
 *   _                   _              _         _         _         _         _
 * _| |______5Tic_______| |____4Tic____| |__3Tic_| |__3Tic_| |_3Tic__| |_3Tic__| |
 *
 *<------delay---------><------delay---------><------delay---------><------delay--------->
 *
 * Attention timer have a response curve like that :
 *
 * | timer frequency
 * |
 * |
 * |
 * |
 * | *
 * |
 * |
 * |
 * |
 * |
 * | *
 * |
 * |
 * |
 * |
 * |   *
 * |
 * |      *
 * |
 * |           *
 * |
 * |                   *
 * |                                     *
 * |                                                                *
 * |------------------------------------------------------------------------------------>
 * Low value timer						high value timer
 *  1                                                               65535
 *
 * This give an acceleration like this if the value is to low
 *
 * speed
 *   |           |________
 *   |          ||
 *   |       ___||
 *   |    __|    |
 *   |   |       |
 *   |  /        |
 * __|/__________|_________
 *               |     time
 *            end acc
 *
 * A smooth acceleration look like this :
 *
 * speed
 *   |           |__________
 *   |          /|
 *   |        /  |
 *   |      /    |
 *   |    /      |
 *   |  /        |
 *___|/__________|__________
 *               |      time
 *            end acc
 *
 *
 ******************************************************************************/
void M_engine()
{
  coil.tic++;
  carriage.tic++;

  switch (M_engineAction)
  {
    case WINDING : //________________________________________________________________________________________________________________________________
      {
	switch(M_isCoilFastest)
	{
	  case true : // Coil have a numbers of steps superior to carriage.
	    {
	      if(coil.tr != M_targetTr)
		{
		  if(coil.tic >= M_speedSet)
		    {
		      coil.tic=0;

		      if(coil.steps != M_stepsPerTr)
			{
			  oneStep(ENABLE , DISABLE); // Coil step depending tic interval.
			  ++coil.steps;
			  ++M_countInterval;

			  if(carriage.steps != M_stepsPerPass)
			    {
			      switch(M_isSuperior)
			      {
				case true : // Blank steps are superiors to half steps per pass.
				  {
				    // Second step : normal distribution.
				    if(carriage.steps >= M_stepsRest && !M_isStepAddMode)
				      {
					M_isStepAddMode = true;
					--M_stepsInterval;
				      }
				    // First step : add a blank step to interval.
				    if(M_countInterval > M_stepsInterval)
				      {
					oneStep(DISABLE, ENABLE);
					++carriage.steps;
					M_countInterval = 0;
				      }
				    break;
				  }
				case false : // Blank steps are inferiors to half steps per pass.
				  {
				    // Second step : add a step to interval.
				    if(carriage.steps > M_stepsAdd && !M_isStepAddMode)
				      {
					M_isStepAddMode = true;
					++M_stepsInterval;
				      }
				    // First step : normal distribution.
				    if(M_countInterval <= M_stepsInterval)
				      {
					oneStep(DISABLE, ENABLE);
					++carriage.steps;
				      }
				    else
				      {
					M_countInterval = 0;
				      }
				  }
			      }
			    }
			}
		      else // Reset counter for next turn.
			{
			  updateCounter();

			  if(carriage.tr == M_targetPass)
			    {
			      carriage.tr = 0;
			      M_invertSense();
			    }
			}
		    }
		}
	      else // End of winding
		{
		  M_stop();
		  M_isFinished = true;
		}

	      break;
	    }
	  case false : // Coil have a numbers of steps inferior to carriage.
	    {
	      // Algorithm is the same that before but motors are inverted.
	      if(coil.tr != M_targetTr)
		{
		  if(carriage.tic >= M_speedSet)
		    {
		      carriage.tic=0;

		      if(carriage.steps != M_stepsPerPass)
			{
			  oneStep(DISABLE , ENABLE);
			  ++carriage.steps;
			  ++M_countInterval;

			  if(coil.steps != M_stepsPerTr)
			    {
			      if(M_isSuperior == true)
				{
				  if(coil.steps >= M_stepsRest && !M_isStepAddMode)
				    {
				      M_isStepAddMode = true;
				      --M_stepsInterval;
				    }

				  if(M_countInterval > M_stepsInterval)
				    {
				      oneStep(ENABLE, DISABLE);
				      ++coil.steps;
				      M_countInterval = 0;
				    }
				}
			      else
				{
				  if(coil.steps > M_stepsAdd && !M_isStepAddMode)
				    {
				      M_isStepAddMode = true;
				      ++M_stepsInterval;
				    }

				  if(M_countInterval <= M_stepsInterval)
				    {
				      oneStep(ENABLE, DISABLE);
				      ++coil.steps;
				    }
				  else
				    {
				      M_countInterval = 0;
				    }
				}
			    }
			}
		      else
			{
			  updateCounter();
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

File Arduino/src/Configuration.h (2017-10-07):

/*
 * Configuration.h
 *
 *  Created on: 26 oct. 2016
 *      Author: jo
 */

#ifndef CONFIGURATIONS_H
#define CONFIGURATIONS_H

// LCD screen definition ------------------------------------------------------
#define LCD_CHARS 16
#define LCD_LINES  2

// Rotary encoder properties --------------------------------------------------
#define ENC_PIN_A	3 // The order declaration(pin A, B) determine the direction.
#define ENC_PIN_B	2 //
#define ENC_PIN_BTN	4 // Click switch
#define ENC_STEP	2 // How many you increase value, when you make one step

// Motors settings ------------------------------------------------------------
#define CLOCK		HIGH
#define C_CLOCK		LOW
#define ENABLE		LOW
#define DISABLE		HIGH

// Steps
//-------------------------
#define MOTOR_STEPS 200
// If you change micros steps you need to change MaxSpeed !
#define FULL_STEPS	1
#define HALF_STEPS	2
#define QUARTER_STEPS	4
#define EIGHTH_STEPS	8
#define SIXTEENTH_STEPS 16
// Setting for micros stepping (make FULL_STEP if you don't use micros stepping)
#define STEPS_PER_TR (MOTOR_STEPS * SIXTEENTH_STEPS)
//-------------------------

// Motor for winding
#define PIN_COIL_DIR	10
#define PIN_COIL_STEP	9
#define PIN_COIL_EN	8

// Mode for carriage
#define PIN_CARR_DIR	7
#define PIN_CARR_STEP	6
#define PIN_CARR_EN	5


// Machine settings ------------------------------------------------------------

// Pitch in mm
//--------------
#define  M3 0.5
#define  M4 0.7
#define  M5 0.8
#define  M6 1
//--------------

#define LEAD_SCREW_PITCH M5 // replace by your own setup.

// Reset value -----------------------------------------------------------------
#define INIT_WIRE	"0.00" 		// in mm
#define INIT_COIL	"000.00"	// in mm
#define INIT_TURNS	"00000"		// in Tr
#define INIT_MAXSPEED	"0200"  // in RPM (tr/min)
#define INIT_MINSPEED	"0001"  // in RPM (tr/min)
#define INIT_ACC_DELAY	"0400"
#define INIT_ACC_INCR	"0020"
#define INIT_W_SENSE	C_CLOCK
#define INIT_C_SENSE	CLOCK

// Displacement value ---------------------------------------------------------------
#define INIT_MOV_CAR	"00.00"
#define INIT_MOV_COIL	"0000"

// Serial Debug option ---------------------------------------------------------
#define DEBUG // Uncomment to active serial debug.
#define BAUDRATE 9600

#endif /* CONFIGURATIONS_H */

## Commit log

2016-08-31 add freecad first freecad files and export stl*
    [centreur.stl, centreur2.stl, coins.stl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]
2016-09-11 Adding kicad files
    [shield_coil-winder.kicad_pcb, shield_coil-winder.sch]
2016-09-14 Adding pulley
2016-09-24 testguide V0.2
    [guideV02-patin.stl, guideV02.stl]
2016-10-07 PCB v1.0
    [shield_coil-winder.sch]
2016-10-08 Image of new guide and pcb V1.0
2016-10-09 V1.1 pcb
    [guideV03-patin.stl, guideV03.stl, shield_coil-winder-drl_map.dxf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]
2016-10-14 First commit arduino V0.1
2016-10-15 Correction label pin on sockets
    [Configuration.h, shield_coil-winder.kicad_pcb, shield_coil-winder.sch]
2016-11-06 v0.12-ok add screen dependance
    [Configuration.h, centreur.stl, centreur2.stl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]
2016-11-12 v0.13-ok fix start deceleration and microstep stepping
    [Configuration.h]
2016-12-02 v0.14-ok begin menu navigation
    [Configuration.h]
2016-12-04 v0.16-ok change name file for edit menu and philosophy
    [Configuration.h]
2016-12-05 change menu setting object (lcd and encoder) and pass funcion in private
2016-12-10 Improve eeprom memory and minor correction on edit menu
    [Display.h, MenuSettings.cpp, MenuSettings.h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]
2016-12-11 continu on eeprom memorie
    [Configuration.h]
2016-12-21 add menuStructures and refresh files
    [Configuration.h]
2016-12-22 Hardware carriage v0.4 and software v0.20
    [guide.stl, guideV02-patin.stl, guideV02.stl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]
2016-12-23 Error on computing() must be reworked
    [Configuration.h]
2016-12-29 v0.21 memory reworked, delete memory object and work only with the class
    [MenuSettings.cpp, MenuSettings.h, Motor.cpp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]
2017-01-09 Add setting, max, min, acc and try to correct acceleration steps
    [Configuration.h]
2017-01-13 Fix calculation of steps deceleration youpi !
    [Display.h, Winding.cpp, main.cpp]
2017-01-14 Use display object in class Setting
    [Configuration.h]
2017-01-17 Rebuild displacement carriage
2017-01-18 Implement first stage for automatic winding
2017-01-18 Add homing() function, to resume start position.
2017-01-19 First work on suspend menu
    [Configuration.h]
2017-01-19 implement back in suspend menu, exit work but need to be reworked
    [Display.h, MenuSettings.cpp, MenuSettings.h]
2017-01-29 Suspend mode and recovery current winding work
2017-01-29 Work on suspend mode
    Fix display value, and resume mode
    [Display.h, MenuSettings.cpp, MenuSettings.h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]
2017-02-01 First implementation for setting current speed
2017-02-01 Update current speed work
2017-02-01 First implementation of save current winding
2017-02-02 Save current winding work
2017-02-02 First implementation of rework menu
    [Display.h, MenuSettings.cpp, MenuSettings.h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]
2017-02-04 cursor displacement not work
    [Display.h, MenuSettings.cpp, MenuSettings.h]
2017-02-11 Fix navigation and selection icons
    [Display.h, MenuSettings.cpp, MenuSettings.h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]
2017-02-14 Ajust menu reset and RAZ (work)
    [Display.h, MenuSettings.cpp, MenuSettings.h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]
2017-02-14 Simple move add
    [Configuration.h]
2017-02-16 Continu rework menu and fix cursor mouvement
    [Display.h, MenuSettings.cpp, MenuSettings.h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]
2017-02-16 add saved and resume function when winding
    [Configuration.h]
2017-02-25 fix steps count
    [Configuration.h]
2017-02-25 Add fastIio.h and change motor control
    [Configuration.h]
2017-03-04 add homing position
2017-03-05 fix resume coil layer
    [MenuSettings.cpp, Save.cpp, Save.h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]
2017-03-05 fix set home move
    [MenuSettings.cpp]
2017-03-12 Change i2c frequency and prepar for new branch
    [Configuration.h, centreur.stl, centreur2.stl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]
2017-03-19 Rework encoder
    [Configuration.h]
2017-08-08 update pio and change timer for encoder
2017-08-08 suppr clamp function and replace by constrain
    [MenuSettings.cpp]
2017-08-08 suppr motors code and start new dev on timerOne
2017-08-08 change define name for pins
    [Configuration.h]
2017-08-12 speed set by rpm
    [Configuration.h]
2017-08-13 carriage displacement is correct
    [Motor.cpp, Winding.cpp]
2017-08-13 add a message fo max speed value
    [Configuration.h]
2017-08-13 add speed ajust with encoder
    [Configuration.h]
2017-08-15 function "move coil or carriage only" is working
2017-08-16 add acc increment setting and acceleration
    [Configuration.h]
2017-08-16 start to add sense of winding
    [Configuration.h]
2017-08-16 homing work
2017-08-17 fix display value when save
    [Display.h, MenuSettings.cpp, Save.cpp]
2017-08-17 prepare for save winding and correct display
    [Display.h, MenuSettings.cpp, Winding.cpp]
2017-08-23 fix sense when save or resume winding
    [MenuSettings.cpp, Motor.cpp, Save.cpp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]
2017-08-27 fix if wire is greter than lead screw pitch
    [Motor.cpp, Winding.cpp]
2017-09-02 homing only carriage not after winding improve
2017-12-29 hardware rework
    [centreur_conique_fixe.stl, centreur_plaque_fixe.stl, entretoise M5 vers M8.stl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]
2017-12-31 stl export
    [Chariot_v0.4-6x10x8.stl, Chariot_v0.4-LM6UU.stl, bride axial.stl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]
2018-01-21 Add pictures and somes *STL files
    [centreur fixe conique.stl, centreur fixe pour plaque.stl, centreur variable.stl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]
